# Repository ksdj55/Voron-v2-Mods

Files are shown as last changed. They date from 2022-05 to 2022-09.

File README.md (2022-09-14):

# Voron-v2-Mods
My Voron v2.4r2 Mods

### 10mm GT2 Z-Belts Mod<br>
My mod to use a locally sourced 10mm GT2 belts and pulleys instead of the 9mm.<p>
### ERCF AB PCB Cover for 23mm motor
Modified ERCF AB Cover for 23mm NEMA17 17HS4023 motor <b>without the toolhead PCB</b>.
### ExhastFanDuct
My designed 60mm exhast fan duct for using washing machine drain tube as exhast duct.
### USB Hub mount
My design to mount a UGreen USB 2.0 Hub to the unused fan slot on Voron 2.4v2

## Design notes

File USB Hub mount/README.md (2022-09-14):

# USB Hub mount for Voron2.4r2
This is my designed for mounting a UGreen USB 2.0 hub to the unused fan slot on Voron v2.4r2.
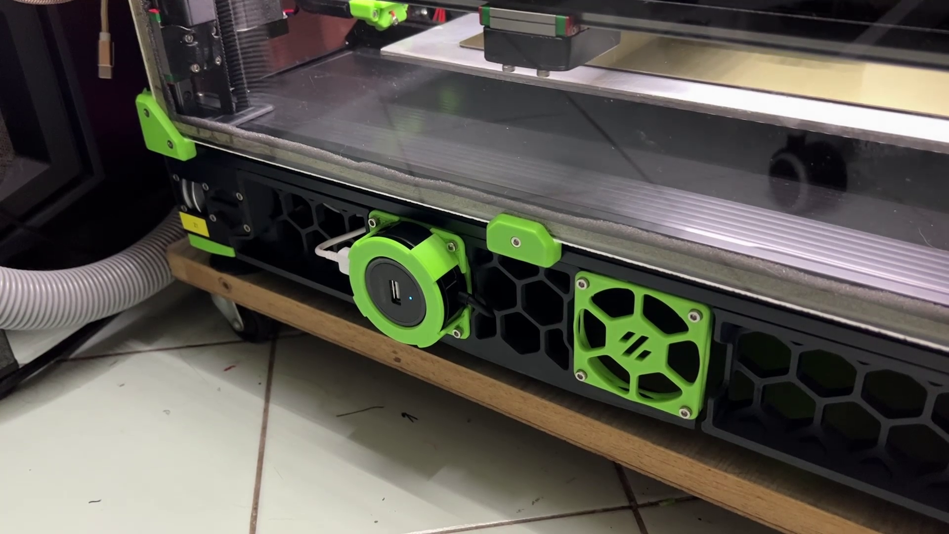
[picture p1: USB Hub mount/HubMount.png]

# Why using a USB Hub?
Because I'm using a Raspberry Pi 2w which has only 1 USB port and want to connect the Octopus board, an Enranged Rabbit Carrot Feeder module and an USB accerometer.
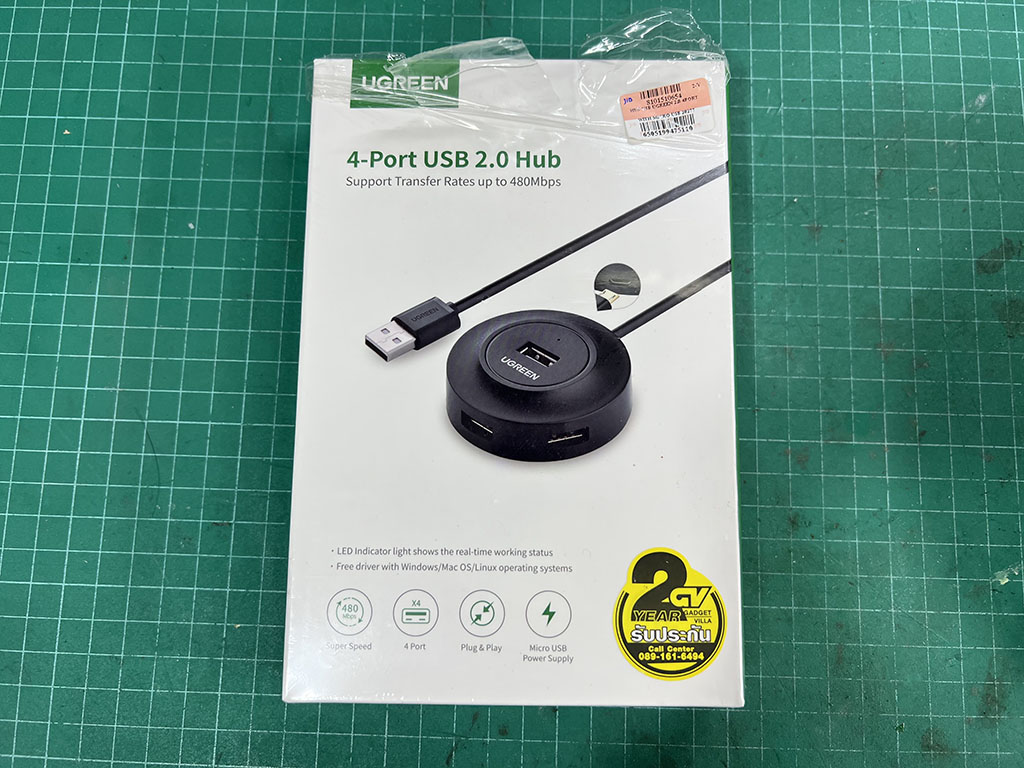
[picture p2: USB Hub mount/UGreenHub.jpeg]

This is a USB hub I'm using, I also include a FreeCAD files so you can modify to suit your need.

Note: Current design is blocking a microUSB power input port on the hub, Some modification is need if you want to use the power in port.

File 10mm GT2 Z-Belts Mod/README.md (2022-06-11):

<b>10mm GT2 Z-Belts Mod (Voron v2.4r2)</b>

During an attempt to self-source a Voron v2.4r2. I've found that the local seller only sell 6mm and 10mm GT2 belt and pulley while the BOM specified a 9mm Z-belt and pulley. So I decieded to go with 10mm belt and pulley only to found out that the pathway through the A and B motor mount was too narrow for a 10mm belt. 

But surprisingly, All the pulley and idler related parts are fine. So I've edit the STL file in blender by slightly enlarged the belt pathway and the gripping notch.

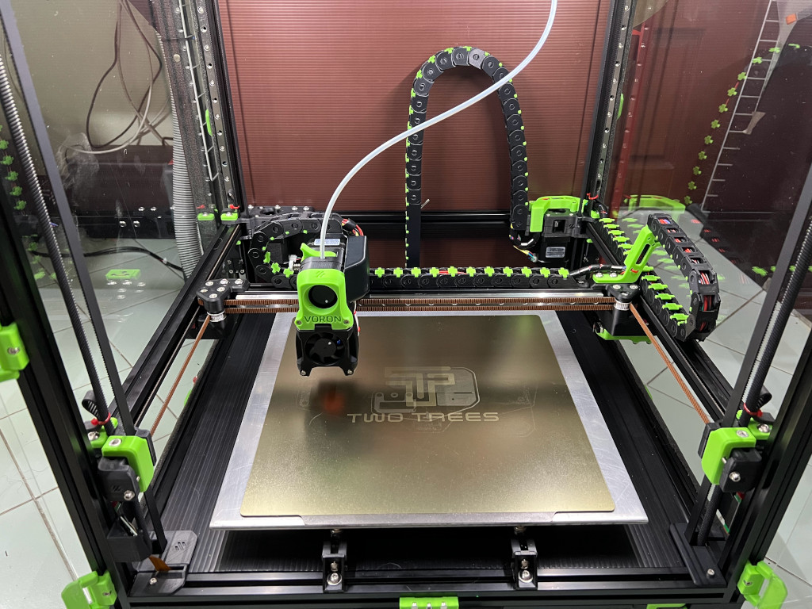
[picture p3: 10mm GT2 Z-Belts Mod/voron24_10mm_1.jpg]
My Voron2.4


My Voron v2.4r2 is now working but is still in process of making so USE AT YOUR OWN RISK.

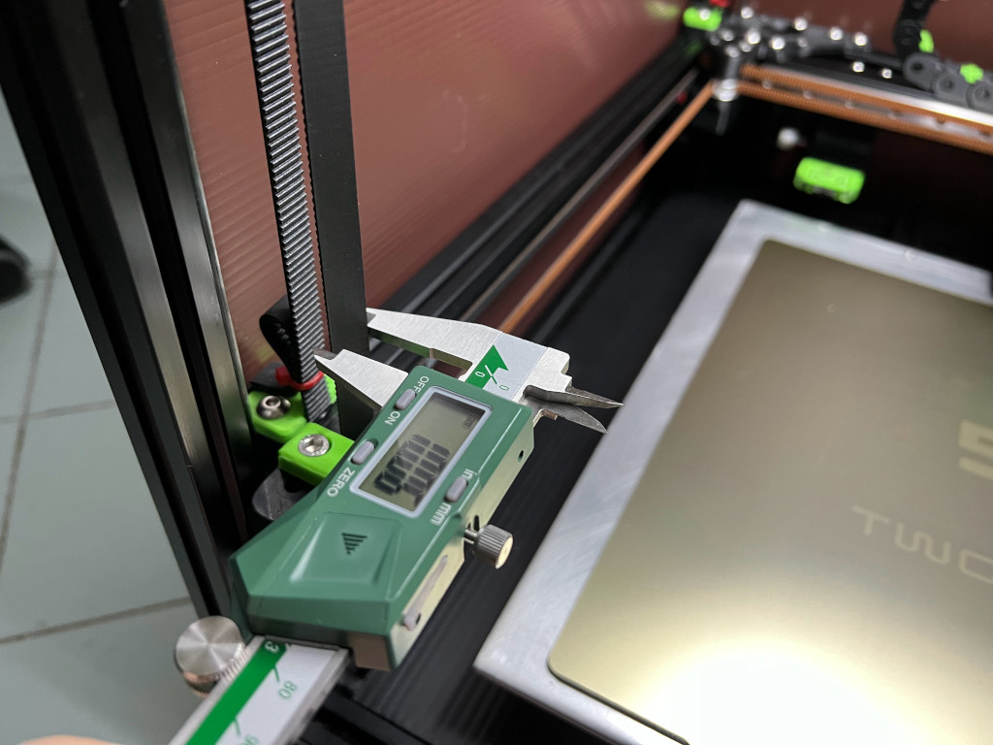
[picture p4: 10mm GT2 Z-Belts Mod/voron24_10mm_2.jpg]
10mm GT2 Belts


<b>FAQ</b><br>
- <b>No CAD files?</b><br>
There is no CAD file on this mod since I don't have a Fusion so I didn't work on the CAD files. I just use a blender to manipulate the STL files.
- <b>Do I need this?</b><br>
Not if you can source a 9mm GT2 belt, But accually, If you already printed the original version you could try to use a hot air to soften the parts and nudge the plastic so the slot are wider but the resulting finish may not be very good.(Don't ask me how I know it.)
- <b>BOM?</b><br>
Just replace all the 9mm GT2 Belt, Pulley, Idler with 10mm parts.

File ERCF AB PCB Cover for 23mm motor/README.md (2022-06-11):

<b>ERCF AB Cover for 23mm motor</b><br>
    This is a my modified version of: 
    
    https://github.com/VoronDesign/Voron-Hardware/blob/master/Afterburner_Toolhead_PCB/STLs/Clockwork/Covers/ERCF_pcb_cover_stock_afterburner.stl
    
<br>    Modified to fit a 23mm long NEMA17 17HS4023 motor <b>without a PCB</b>, if you're using a ERCF PCB then please use a spacer rod from the original file (or just trim off as needed).

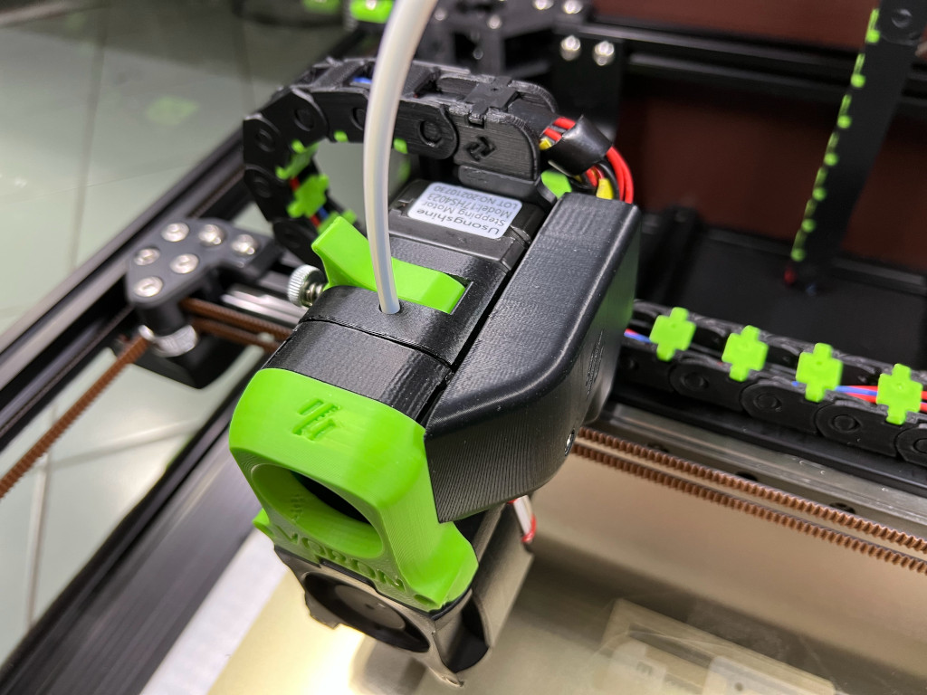
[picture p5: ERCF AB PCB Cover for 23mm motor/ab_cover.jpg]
Afterburner Cover


<br>    Note: In order to use a 17HS4023 motor in Afterburner you need to cut or grind the motor shaft 2 mm. Also the motor back is 3 mm longer and may cause some chain to not align perfectly. (I use PanzerChain)

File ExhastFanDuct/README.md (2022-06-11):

# Exhaust Fan Duct for Voron2.4r2
This is my designed 60mm fan duct adapter for using a washing machine drain tube as a exhaust duct, The OD of connecting mount is 37.5 mm.
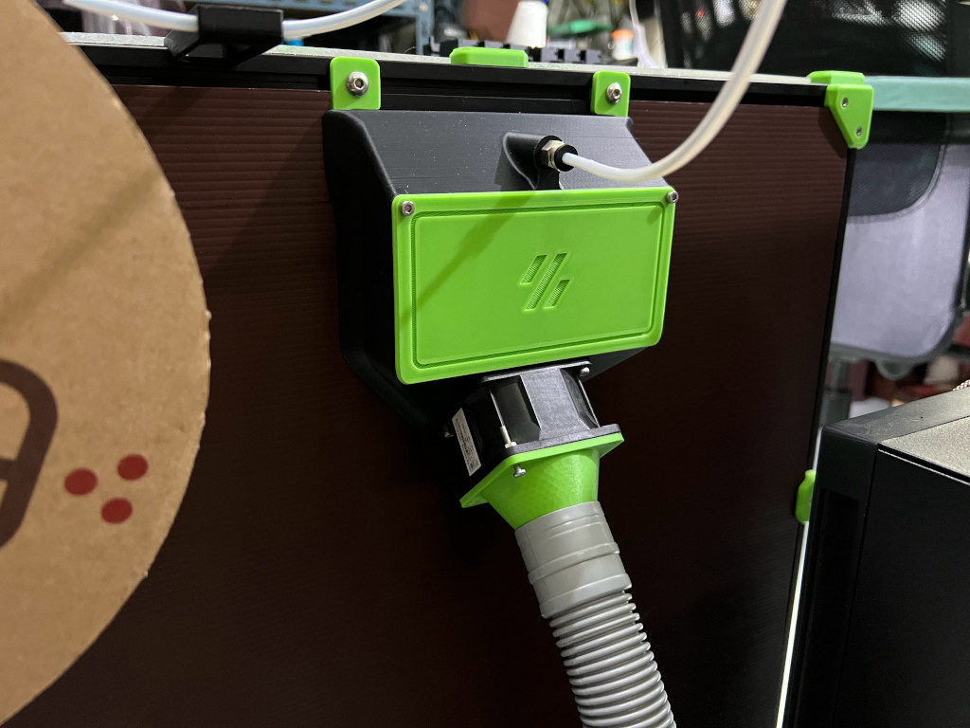
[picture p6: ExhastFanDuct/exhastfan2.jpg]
Fan Duct

<p>Please noted that the washing machine tube is small diameter and has a high resistant which mean either you use a very short tube (less than 1 meter) or you will need a powerful server fan (high static pressure) to push a pratical amount of air through.<p>
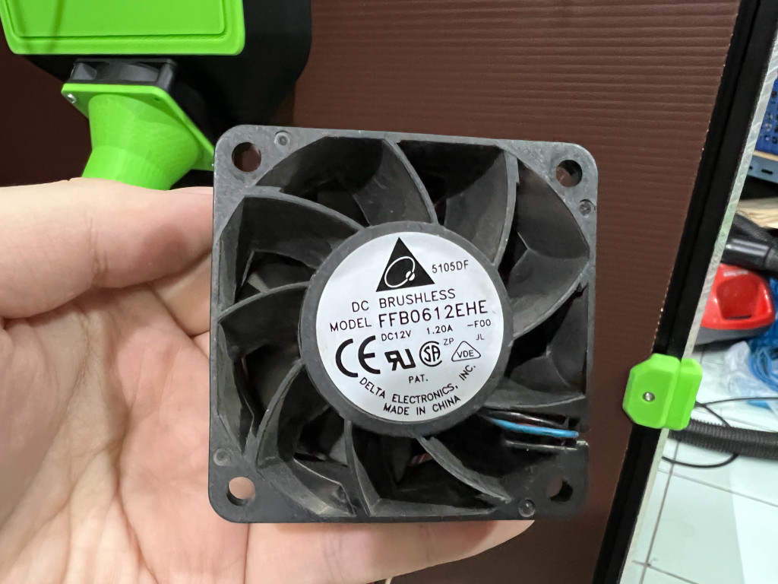
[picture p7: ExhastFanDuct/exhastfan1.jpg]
Exhast fan

    <p>I use 3 meter tube with a Delta 12v 1.2A ex-server fan (see photo) run directly off the BTT Octopus v1.1 board.
    Also included a FreeCAD file so you can modify it to fit.

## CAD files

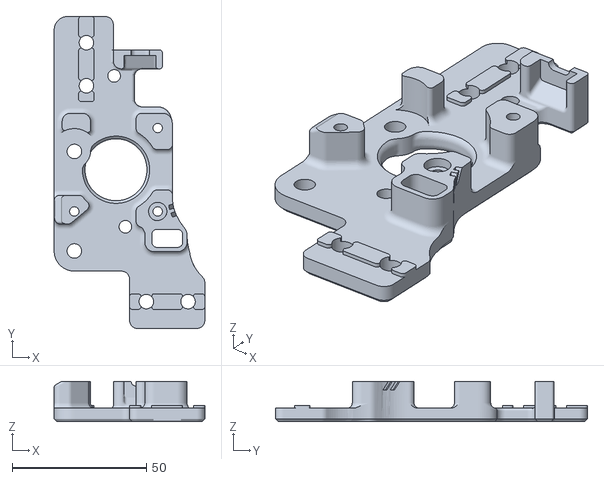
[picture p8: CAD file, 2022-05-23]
10mm GT2 Z-Belts Mod/voron2.4r2 10mmGT2 Mod-A_Drive_Frame_Upper.stl
56.0 x 116.0 x 15.0

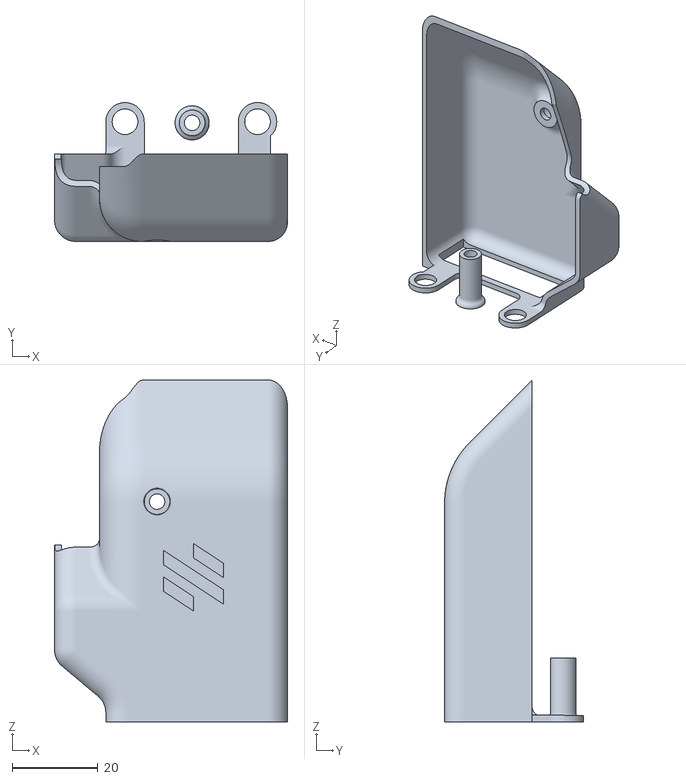
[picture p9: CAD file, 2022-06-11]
ERCF AB PCB Cover for 23mm motor/ERCF AB PCB cover 23mm mod-ERCF_pcb_cover_stock_afterburner_23mm.stl
54.5 x 32.5 x 80.0

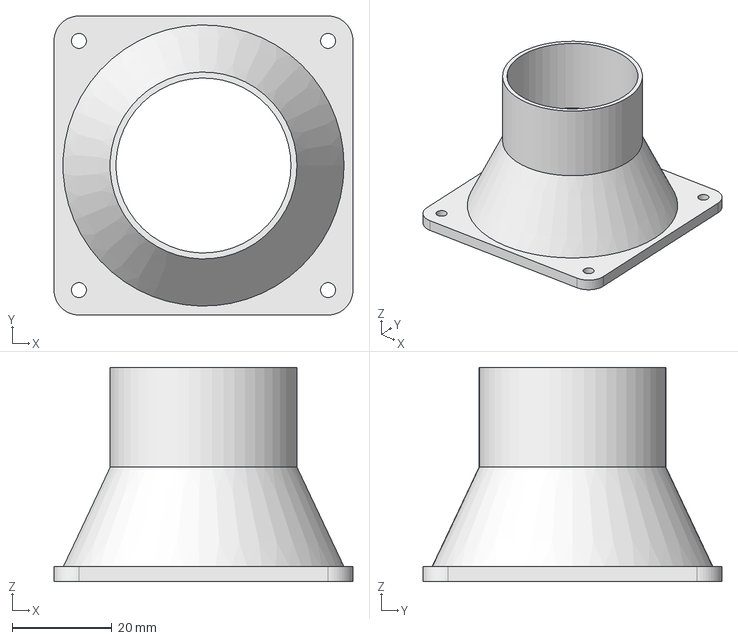
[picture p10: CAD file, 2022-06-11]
ExhastFanDuct/60fanDuctAdapter.FCStd
60.0 x 60.0 x 43.0 mm

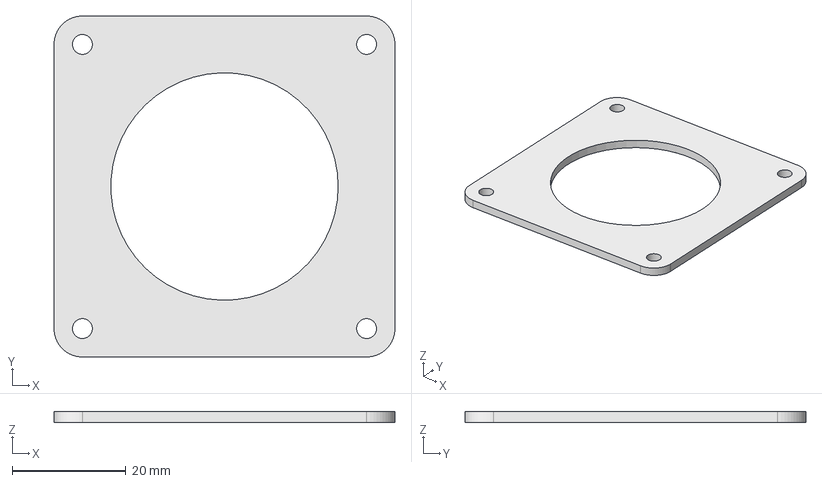
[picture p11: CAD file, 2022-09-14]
USB Hub mount/usbHubMount.FCStd
60.0 x 60.0 x 2.00 mm

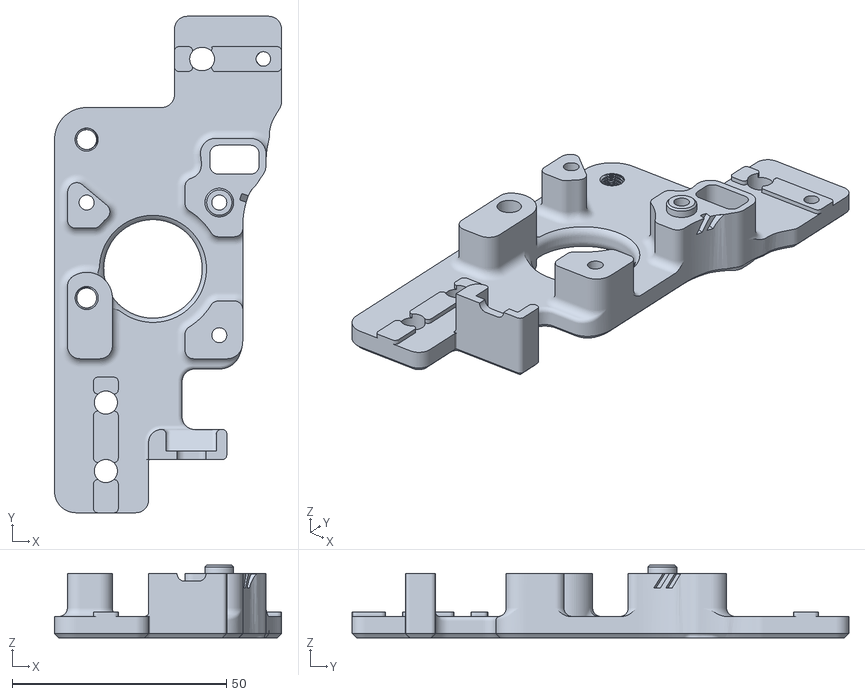
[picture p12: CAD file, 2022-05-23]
10mm GT2 Z-Belts Mod/voron2.4r2 10mmGT2 Mod-A_Drive_Frame_Lower.stl
53.0 x 116.0 x 17.0

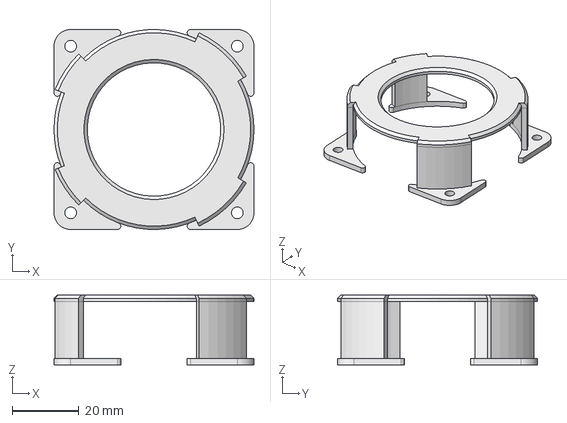
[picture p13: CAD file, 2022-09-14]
USB Hub mount/usbHubMount2.FCStd
60.0 x 60.0 x 21.0 mm

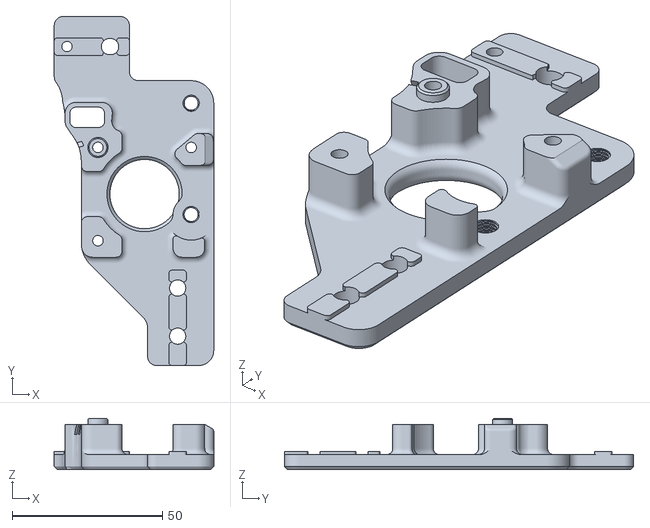
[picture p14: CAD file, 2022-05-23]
10mm GT2 Z-Belts Mod/voron2.4r2 10mmGT2 Mod-B_Drive_Frame_Lower.stl
53.0 x 116.0 x 17.0

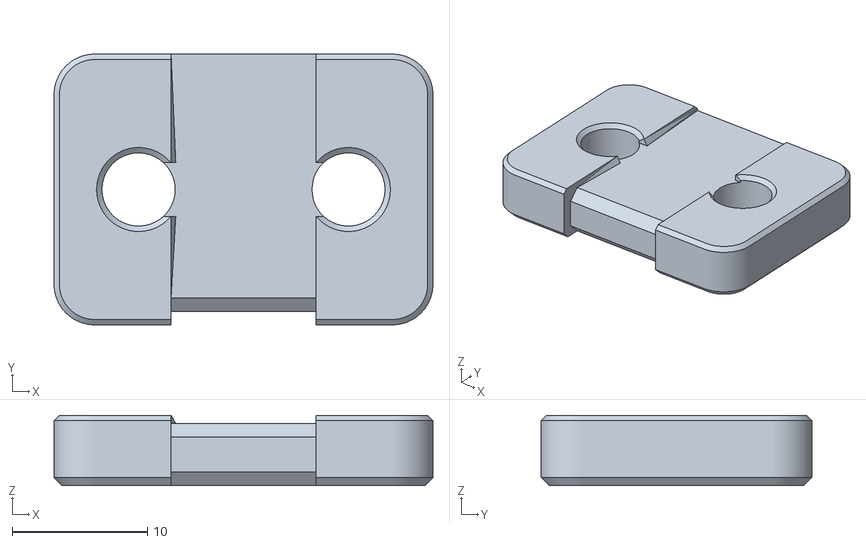
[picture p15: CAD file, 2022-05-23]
10mm GT2 Z-Belts Mod/voron2.4r2 10mmGT2 Mod-_A__Z_Belt_Clip_Upper_X4.stl
28.0 x 20.0 x 5.20

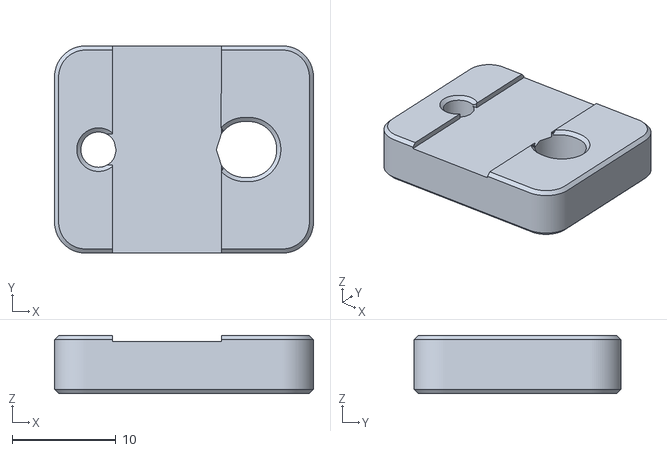
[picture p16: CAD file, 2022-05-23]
10mm GT2 Z-Belts Mod/voron2.4r2 10mmGT2 Mod-_A__Z_Belt_Clip_Lower_X4.stl
25.0 x 20.0 x 5.60

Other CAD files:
USB Hub mount/usbHubMount1.stl
10mm GT2 Z-Belts Mod/voron2.4r2 10mmGT2 Mod-B_Drive_Frame_Upper.stl
ExhastFanDuct/60fanDuctAdapter.stl
USB Hub mount/usbHubMount2.stl

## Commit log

2022-05-23 - Added STL files for 10mm GT2 Z-Belts Mod.
    [voron2.4r2 10mmGT2 Mod-A_Drive_Frame_Lower.stl, voron2.4r2 10mmGT2 Mod-A_Drive_Frame_Upper.stl, voron2.4r2 10mmGT2 Mod-B_Drive_Frame_Lower.stl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]
2022-06-11 - Added ERCF AB PCB Cover for 23mm motor.
    [ERCF AB PCB cover 23mm mod-ERCF_pcb_cover_stock_afterburner_23mm.stl]
2022-06-11 - Add Photos. - Add 60mm Fan Duct Adapter
    [60fanDuctAdapter.FCStd, 60fanDuctAdapter.stl]
2022-06-11 fix misspelling
    [60fanDuctAdapter.FCStd, 60fanDuctAdapter.stl]
2022-09-14 - Add USB Hub mount.
    [usbHubMount.FCStd, usbHubMount1.stl, usbHubMount2.FCStd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]
